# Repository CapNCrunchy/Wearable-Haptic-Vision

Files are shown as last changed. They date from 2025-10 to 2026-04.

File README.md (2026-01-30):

# Wearable-Haptic-Vision
Capstone project for UF CpE

# Project Architecture
"Wearable Haptic Vision" is a device that uses a wearable tactile display to inform the wearer about their surroundings by receiving object distance information. It will capture LiDAR depth information and utilize a Raspberry controller unit to make the wearable pressure waistband react according to an object's distance and direction.

## Pressure Waistband
The waistband will have embedded inflatable nodes that each have tubing connecting to a main housing unit that will hold the intake/exhaust controls (logic circuitry, pressure sensors, raspberry pi). There are 8 nodes that go across the waist and each will inflate according to the corresponding lidar information. For example, if an object is very close to the right side of the Lidar then the nodes on the right side will inflate to the max to represent the closest object. The inverse is also true that an object that is far away will be represented by a very deflated node.

## LiDAR Application
It is an iOS swift application taht utilizes the iphone built in LiDAR to retrieve location and distance information. It takes it as a full image map and then averages the values within the corresponding divisions. This is sent to the Raspberry Pi controller via BLE.

## Controller
The Raspberry Pi takes the lidar data and simplifies it into four states by distance. It then sends this data to the pressure regulator logic which switches between intake and exhaust to get to the correct state. This gives each node four distance/pressure states. 

# Completed Work 
- BLE reciever and Swift application connection
- Infalte/deflate valves for nodes
- Inflate/deflate Schematics w/ Rasperbery pi & modules
- Swift IOS application to interface with LIDAR
- Schematics and models for the vest & soft 3d-printed nodes

# Known Bugs/WIP
The newest physical model of inflatables and circuitry is still waiting to be printed.

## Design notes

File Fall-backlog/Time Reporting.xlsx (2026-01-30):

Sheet: Sheet1
Name | Date | Punch In | Punch Out | Description of Work
Connor | 2025-10-10 | 13:00:00 | 17:00:00 | Research on vest module options
Nico | 2025-10-14 | 17:00:00 | 18:00:00 | Research on sensor options for depth estimation, reaching out to researcher and consultants
Elias | 2025-10-16 | 12:30:00 | 12:55:00 | Researching interfacing with the built in iPhone lidar through swift and libraries and reaching out to MIT researchers related to our project
Connor | 2025-10-18 | 1:00:00 | 1:45:00 | Ordering parts and Outreach
Nico | 2025-10-24 | 15:00:00 | 19:00:00 | Researching and designing vest and soft nodes
Connor | 2025-10-24 | 20:30:00 | 22:00:00 | Hardware setup
Elias | 2025-10-24 | 21:00:00 | 0:00:00 | Reseraching and test runngin setting up Connection with Pi to iPhone through BLE
Shiner | 2025-10-24 | 22:00:00 | 0:45:00 | Researching PI and BLE
Elias | 2025-10-25 | 14:00:00 | 17:00:00 | Successfully configure Bluetooth on the Raspberry Pi 5
Shiner | 2025-10-25 | 14:00:00 | 17:00:00 | Troubleshooting iPhone and Pi bluetooth connection
Connor | 2025-10-25 | 17:00:00 | 19:00:00 | Researching Microcontroller feedback loop
Nico | 2025-10-25 | 17:00:00 | 19:00:00 | Designing soft nodes
Elias | 2025-10-25 | 18:00:00 | 22:00:00 | Deep Dive into Blue with Raspberry Pi reading documentation from argenox.com attempted some barebones scripts
Connor | 2025-10-26 | 5:00:00 | 10:00:00 | Soldering smd components. Microcontroller setup
Nico | 2025-10-26 | 13:00:00 | 14:00:00 | Designing and outreach
Shiner | 2025-10-26 | 16:00:00 | 19:00:00 | Testing and finishing up the BLE connection
Nico | 2025-10-26 | 17:00:00 | 23:00:00 | Cleaning up models and researching materials
Connor | 2025-10-26 | 16:00:00 | 22:30:00 | Full setup for a single node and schematic design
Shiner | 2025-10-26 | 19:15:00 | 21:30:00 | Confirming iPhone connection to Pi is seamless and efficient and cleaning up
Elias | 2025-10-26 | 14:00:00 | 18:30:00 | Finally Fixed WiFi problem with the Pi had to add Wifi Sharing from my laptop through the correct ethernet port updated some code to have correct logging functionality
Elias | 2025-10-26 | 19:15:00 | 21:30:00 | Completed the BLE receiver code and successfully demonstrated it
Connor | 2025-11-02 | 10:00:00 | 12:00:00 | Tubing set up
Connor | 2025-11-06 | 5:00:00 | 17:00:00 | Tubing, breadboarding, and physical prototype skeleton
Shiner | 2025-11-06 | 15:00:00 | 17:30:00 | Reviewing BLE connection and researching BLE GATT for Pi to microcontroller setup
Elias | 2025-11-07 | 16:00:00 | 21:00:00 | Research and reviewed SPI communication between the Pi and feather microcontroller and created a skeleton code template for storing the JSON payload
Nico | 2025-11-08 | 0:00:00 | 4:00:00 | Tubing and pneumatics setup/ math
Shiner | 2025-11-08 | 14:00:00 | 17:15:00 | Looked at skeleton code for storing JSON payload and researched how to incorporate it into microcontroller
Nico | 2025-11-09 | 11:00:00 | 13:00:00 | Consulting and research
Shiner | 2025-11-10 | 12:00:00 | 17:30:00 | Investigated and researched methods for converting LiDAR proximity values into discrete pressure levels based on actuator constraints
Elias | 2025-11-11 | 11:00:00 | 17:00:00 | Did in depth review of gRPC - Protobuf in case we needed to have a server for observation alongside our BLE
Shiner | 2025-11-11 | 16:00:00 | 20:00:00 | Understanding Rust language and tooling to prepare for receiver implementation
Shiner | 2025-11-11 | 21:00:00 | 23:30:00 | Reviewed BLE constraints for transmitting LiDAR grid data and compared JSON vs compact binary formats to prepare for later implementation.
Nico | 2025-11-13 | 14:30:00 | 18:00:00 | Redesigning node and research on flat pneumatic actuator
Shiner | 2025-11-13 | 19:00:00 | 22:00:00 | Researched JSON deserialization approaches and example 2D array validation techniques in Rust
Nico | 2025-11-14 | 1:00:00 | 3:00:00 | Assembly of pneumatics
Elias | 2025-11-14 | 14:00:00 | 18:00:00 | Attempted to solve connections issues with the pi and computers which we trying to develope with, bought a new hdmi cable which was incorrect, then finally returned it and bought a micro hdmi cable for the pi and solved all dev issues
Connor | 2025-11-14 | 17:30:00 | 18:00:00 | Micro controller code
Shiner | 2025-11-14 | 20:00:00 | 0:00:00 | Reviewed microcontroller code and researched the correct 2 value state patterns needed to support four pressure levels per node.
Connor | 2025-11-15 | 12:30:00 | 19:00:00 | Lab testing with compressed air and end to end connections
Shiner | 2025-11-15 | 14:00:00 | 20:00:00 | Implemented and completed JSON parsing, grid validation, and node state mapping, debugged for a while to fix issue with listening on wrong inferface
Elias | 2025-11-15 | 15:00:00 | 20:00:00 | Reseraching SPI protocols and did very extensive debugging to finally discover we were listening on if00 not if01
Nico | 2025-11-15 | 22:00:00 | 2:00:00 | Flat Pneumatic casting
Nico | 2025-11-16 | 14:00:00 | 19:00:00 | Testing first rounds of pneumatic casts and casting 2nd round
Elias | 2025-11-16 | 15:00:00 | 20:30:00 | Attempting to develope a more effeciently threaded Rust file to reduce the latency from the iphone down to the communication chain to the microcontroller

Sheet: Colin Hours
Start Date | Start Time | End Date | End Time | Duration (h) | Description
14/11/2025 | 15:00:00 | 14/11/2025 | 19:00:00 | 4:00:00 | Helped test LiDAR application + BLE receiver functionality in tandem with the pressure node system
14/11/2025 | 10:00:00 | 14/11/2025 | 17:00:00 | 7:00:00 | Implemented LiDAR + node grid processing in the iPhone application, fixed BLE transmissions with Raspberry Pi
13/11/2025 | 14:00:00 | 13/11/2025 | 17:00:00 | 3:00:00 | Researched LiDAR implementation methods and helped set up Raspberry Pi in lab
26/10/2025 | 13:00:00 | 26/10/2025 | 16:00:00 | 3:00:00 | Finished BLE transmissions
24/10/2025 | 11:00:00 | 24/10/2025 | 13:00:00 | 2:00:00 | Set up remote connections to Raspberry Pi for debug, set up user accounts for others to access
23/10/2025 | 12:00:00 | 23/10/2025 | 16:00:00 | 4:00:00 | Researched methods for receiving BLE messages, developed prototype receiving for verifying interface
20/10/2025 | 12:00:00 | 20/10/2025 | 14:30:00 | 2:30:00 | Develop initial LiDAR interface with BLE discovery functionality
19/10/2025 | 10:30:00 | 19/10/2025 | 12:00:00 | 1:30:00 | Initialize swift project, documentation reading (Swift UI and CoreBluetooth SDK)
18/10/2025 | 15:00:00 | 18/10/2025 | 15:30:00 | 0:30:00 | Provisioned Raspberry Pi 5 with Raspberry Pi OS Lite, configured and troubleshooted SSH connectivity
18/10/2025 | 11:00:00 | 18/10/2025 | 14:00:00 | 3:00:00 | Formulated problem of projecting LiDAR depth map to an i x j pressure grid, researched ways of extracting LiDAR depth map from iOS app, drafted high-level architecture for system
16/10/2025 | 13:00:00 | 16/10/2025 | 16:00:00 | 3:00:00 | Researched communication methods for iPhone and Raspberry Pi, compared approaches for continuous data streaming and discrete sensor commands from iPhone LiDAR

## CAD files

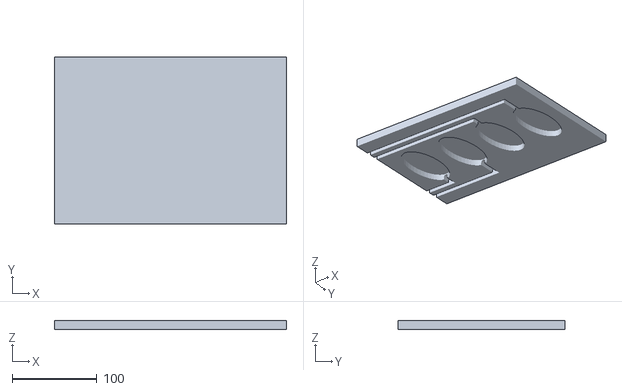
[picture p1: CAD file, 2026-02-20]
3d-models-drawings/new_models/grid nodes assembly file/Assembly 1 - tpu.stl
274.0 x 197.8 x 11.0

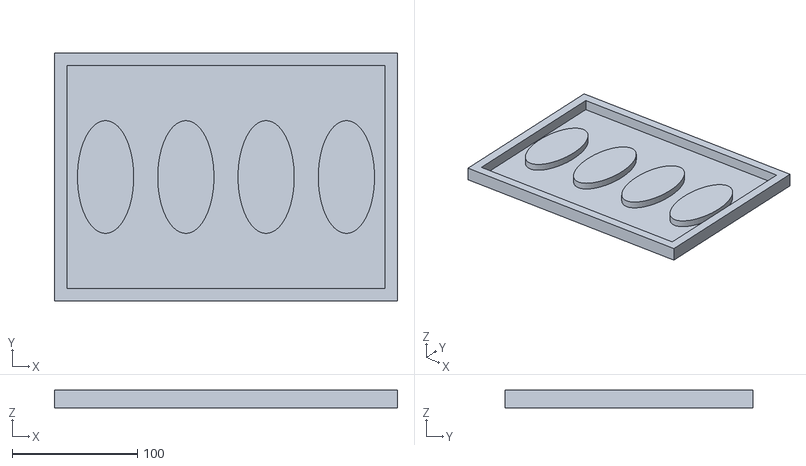
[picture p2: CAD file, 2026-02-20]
3d-models-drawings/new_models/grid nodes assembly file/Assembly 1 - silicone.stl
274.0 x 197.8 x 14.0

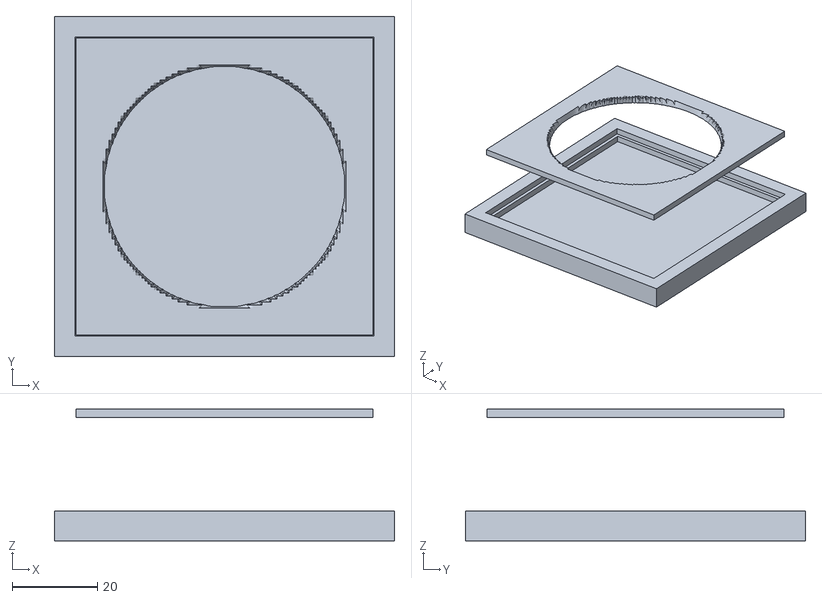
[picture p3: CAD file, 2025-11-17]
3d-models-drawings/flat_actuators_both20251113-43-4bq0js.stl
80.0 x 80.0 x 31.0

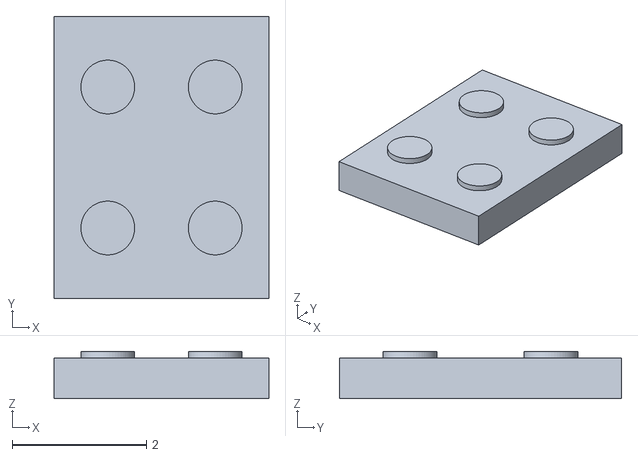
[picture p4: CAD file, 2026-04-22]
3d-models-drawings/new_models/external-ui-remote-v.01.stl
3.20 x 4.20 x 0.7

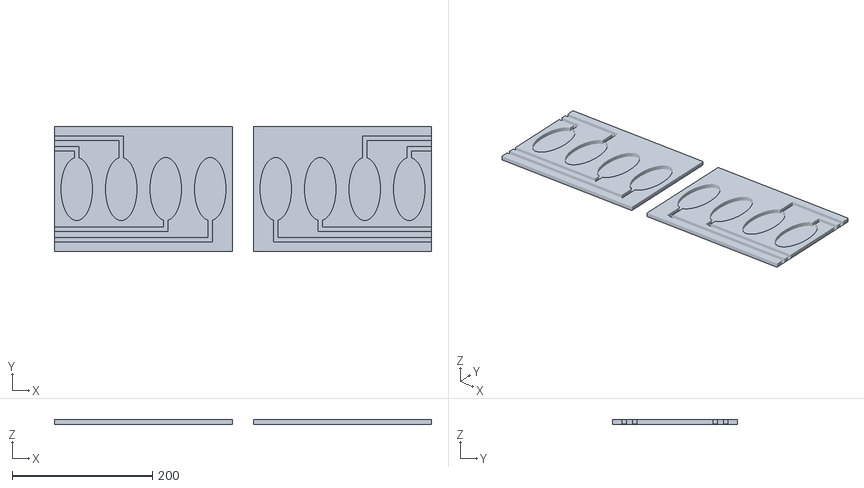
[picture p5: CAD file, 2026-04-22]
3d-models-drawings/new_models/grid nodes assembly file/new-grid-8.stl
538.0 x 177.8 x 6.50

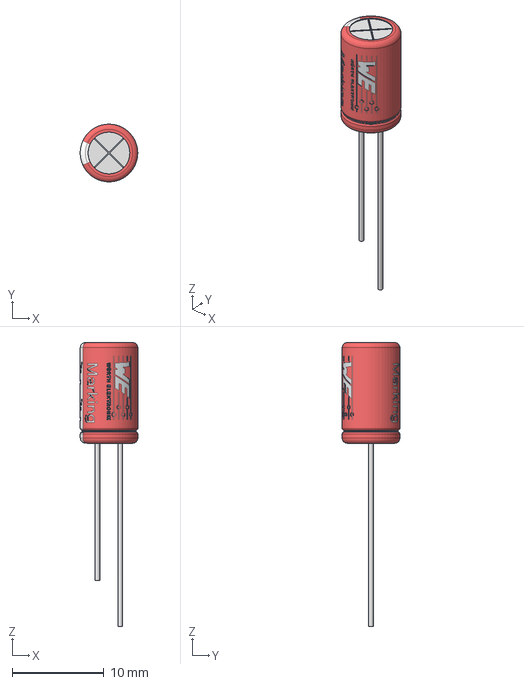
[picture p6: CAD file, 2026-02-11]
hardware/WHV_design/additional_footprints/860040573004/WCAP-ATUL_6.3X11.step
6.29 x 6.30 x 31.0 mm

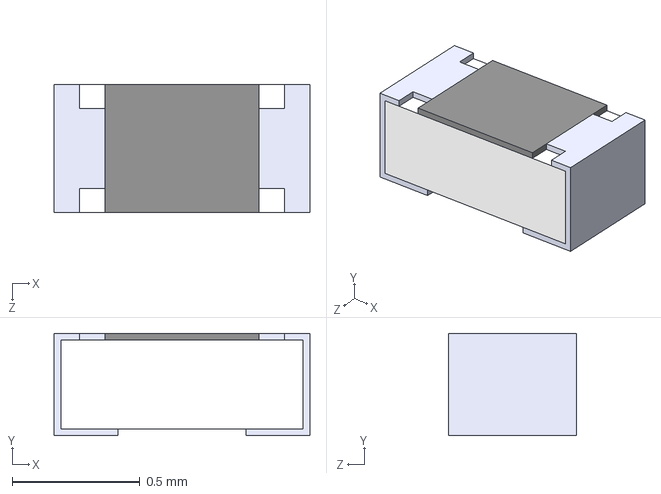
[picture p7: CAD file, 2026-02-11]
hardware/WHV_design/additional_footprints/RC0402FR_07210RL/RC0402FR-07210RL.step
1.00 x 0.4 x 0.5 mm

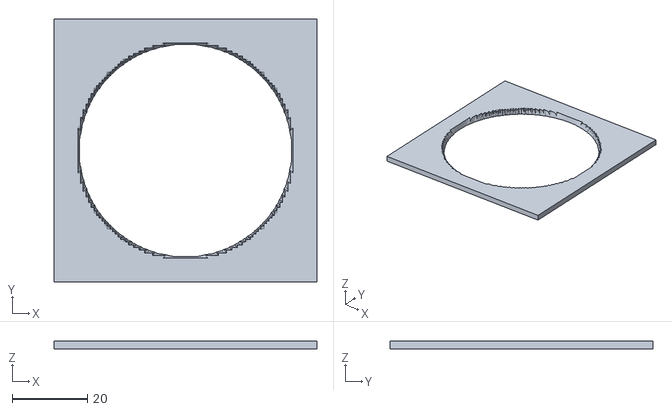
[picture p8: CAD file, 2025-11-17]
3d-models-drawings/flat_actuators_second20251113-43-1qi1enx.stl
70.0 x 70.0 x 2.00

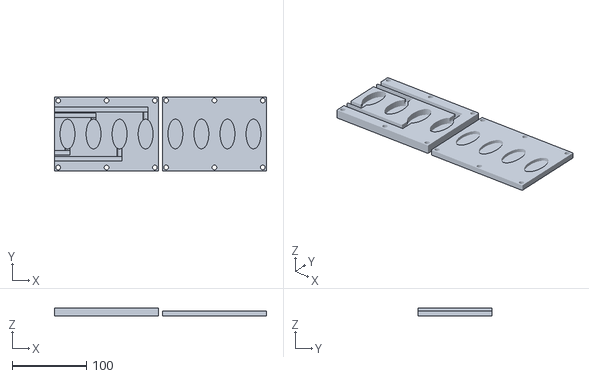
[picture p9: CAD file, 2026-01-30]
3d-models-drawings/new_models/grid_nodes_edited_v1.stl
285.1 x 100.1 x 11.4

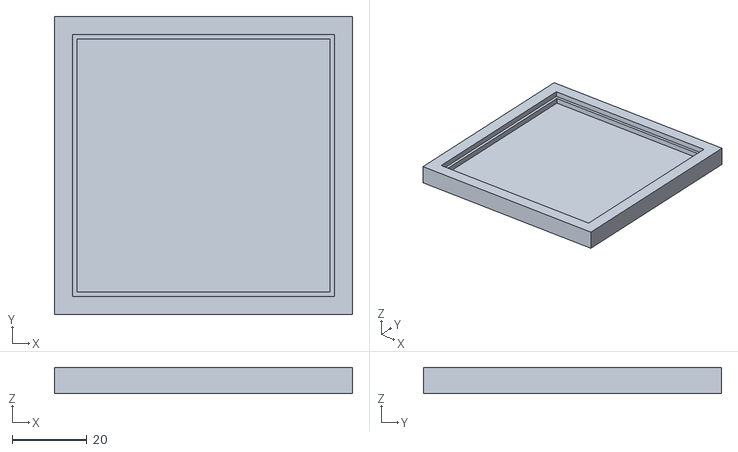
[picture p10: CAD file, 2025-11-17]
3d-models-drawings/flat_actuators_first20251113-43-1jmwba1.stl
80.0 x 80.0 x 7.00

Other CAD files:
3d-models-drawings/soft_pressure_node_part.sldprt
3d-models-drawings/old_drawings/soft_pressure_node_part.sldprt

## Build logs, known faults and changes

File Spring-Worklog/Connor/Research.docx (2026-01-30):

1/28/26 – 1/29/26

Summary: Looked at compressed air options and compatibility. Explored a mutable and modular schematic for valve control and decided to reduce project scope to accommodate lower engineering complexities. Created designed pressure control circuit to cut out the microcontroller in favor of just the pi.

Compressed air Research:

https://www.vevor.com/diving-snorkeling-c_13730/vevor-mini-scuba-tank-0-5l-portable-diving-tank-for-underwater-breathing-reusable-lung-diving-cylinder-up-to-10-minut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

https://www.homedepot.com/p/VEVOR-PCP-Hand-Pump-4-Stage-30Mpa-4500-PSI-High-Pressure-PCP-Air-Rifile-Filling-Stirrup-Pump-for-Airguns-Scuba-Tank-SDQQCQB4000PSVH1RV0/3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

Circuit stuff:

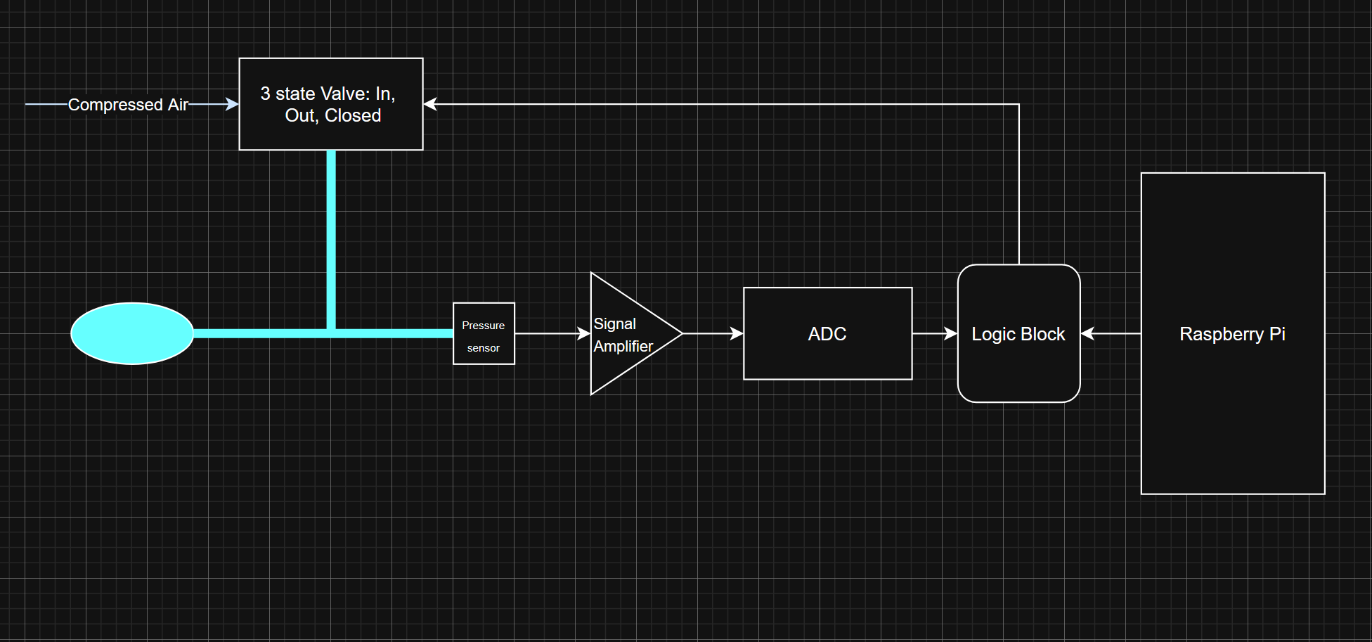
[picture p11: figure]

Handwritten notes and scratch:

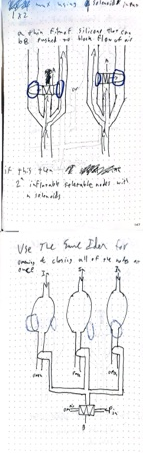
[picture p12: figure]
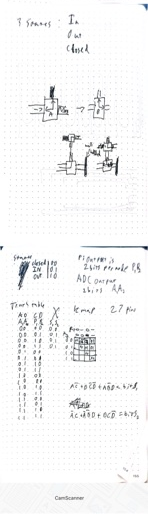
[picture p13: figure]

1/30

The schematic is the pressure sensor, amplifier, flash ADC, and logic to control the 2 valves for 3 states; IN, OUT, CLOSED.

The idea is that the pressure sensor output is put through amplifiers, then a differential and then put through a flash ADC to get the value in one of four states. The logic output is to control the two solenoid valves to create 3 different states. This is based on the ADC value and the raspberry Pi assigned value.

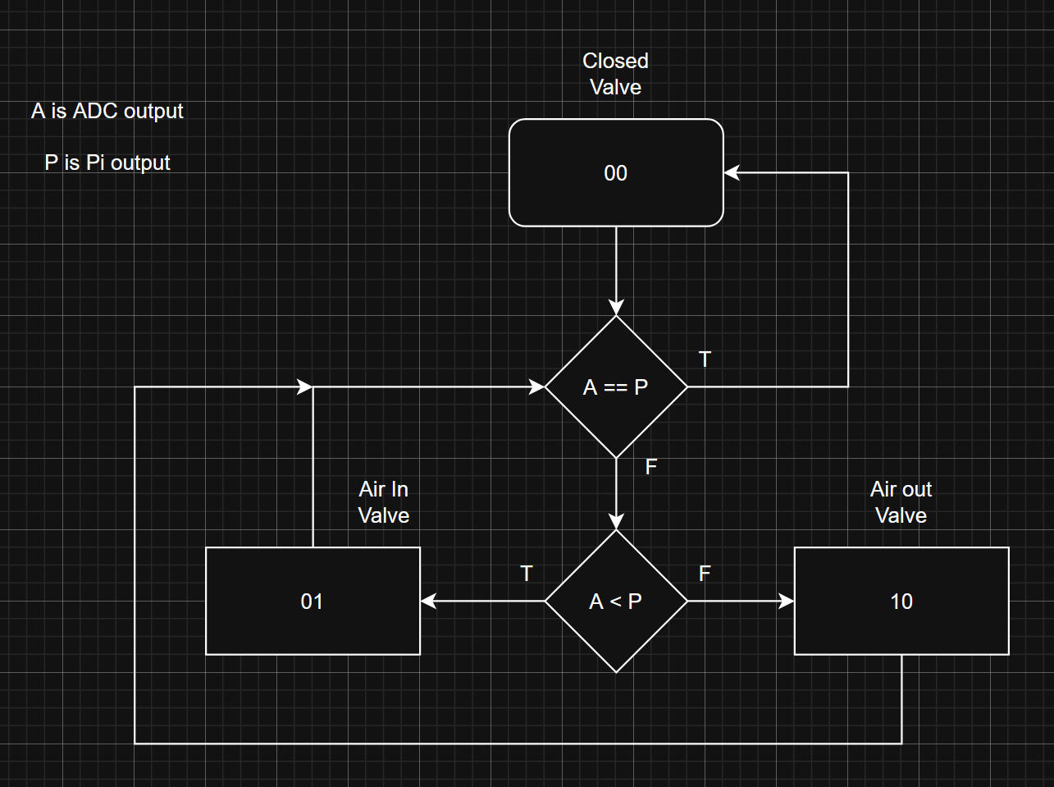
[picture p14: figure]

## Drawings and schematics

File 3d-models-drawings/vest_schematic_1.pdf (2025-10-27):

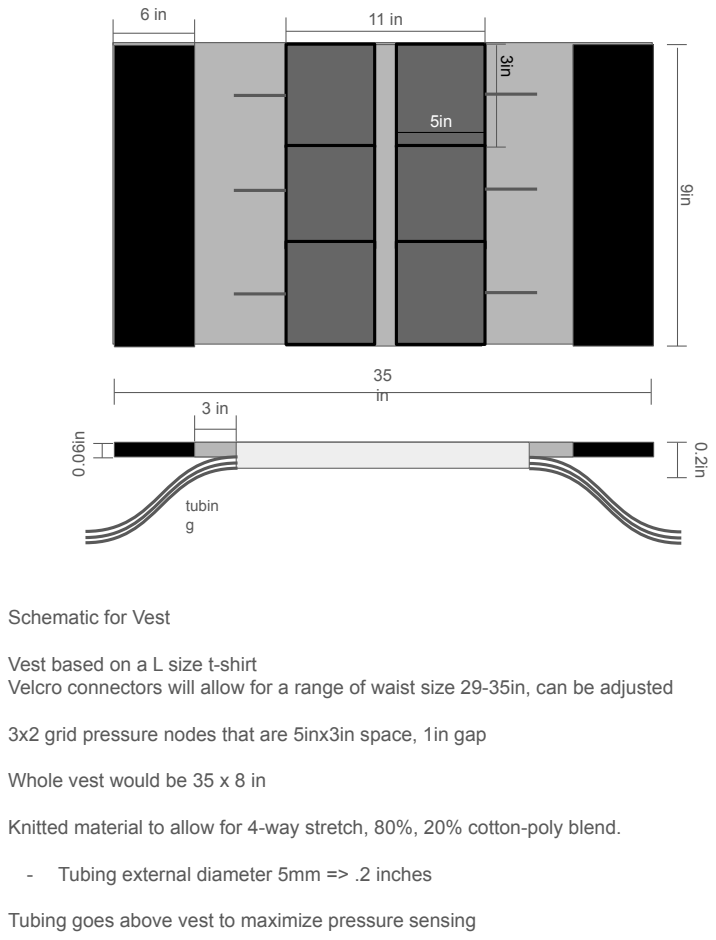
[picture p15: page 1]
tubin g

Schematic for Vest

Vest based on a L size t-shirt
Velcro connectors will allow for a range of waist size 29-35in, can be adjusted

3x2 grid pressure nodes that are 5inx3in space, 1in gap

Whole vest would be 35 x 8 in

Knitted material to allow for 4-way stretch, 80%, 20% cotton-poly blend.

- Tubing external diameter 5mm => .2 inches

Tubing goes above vest to maximize pressure sensing

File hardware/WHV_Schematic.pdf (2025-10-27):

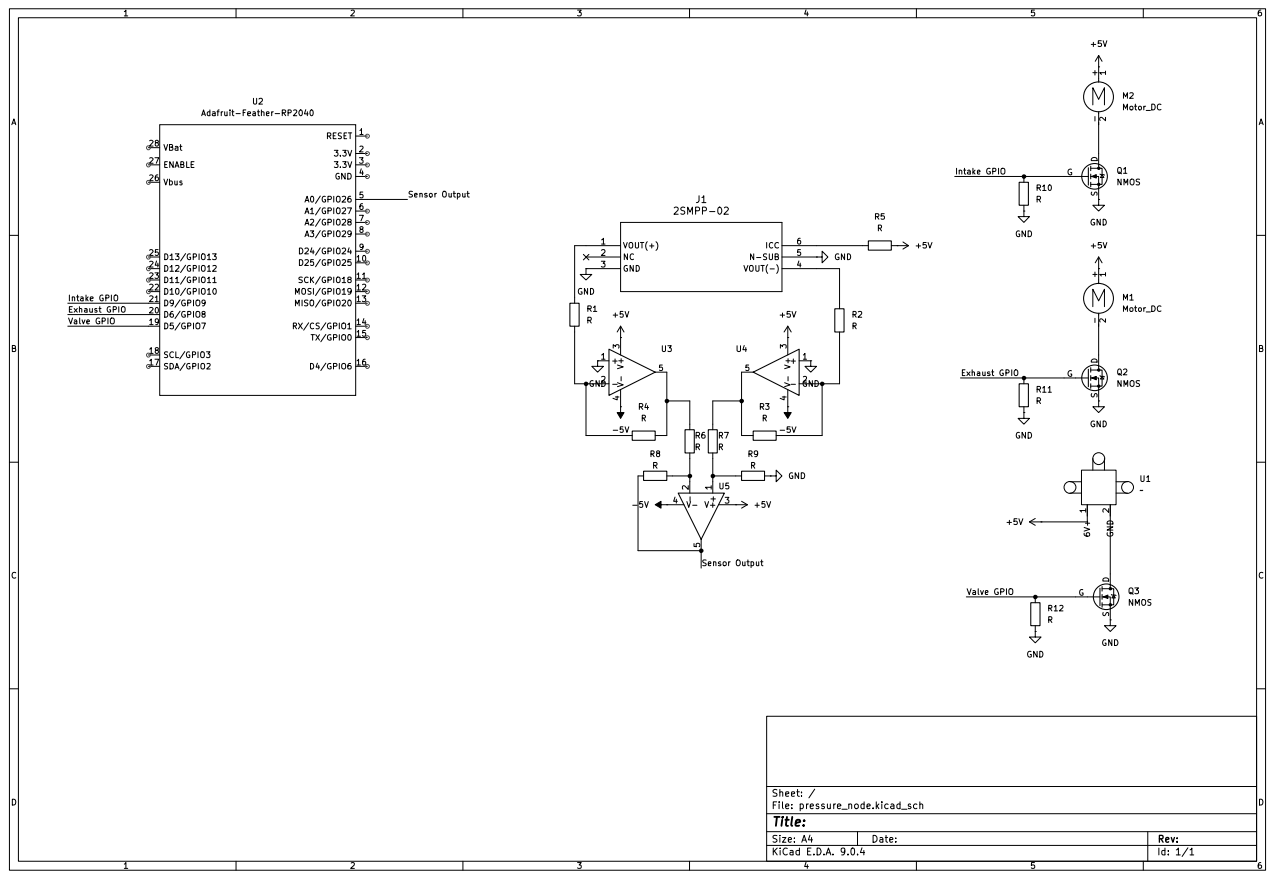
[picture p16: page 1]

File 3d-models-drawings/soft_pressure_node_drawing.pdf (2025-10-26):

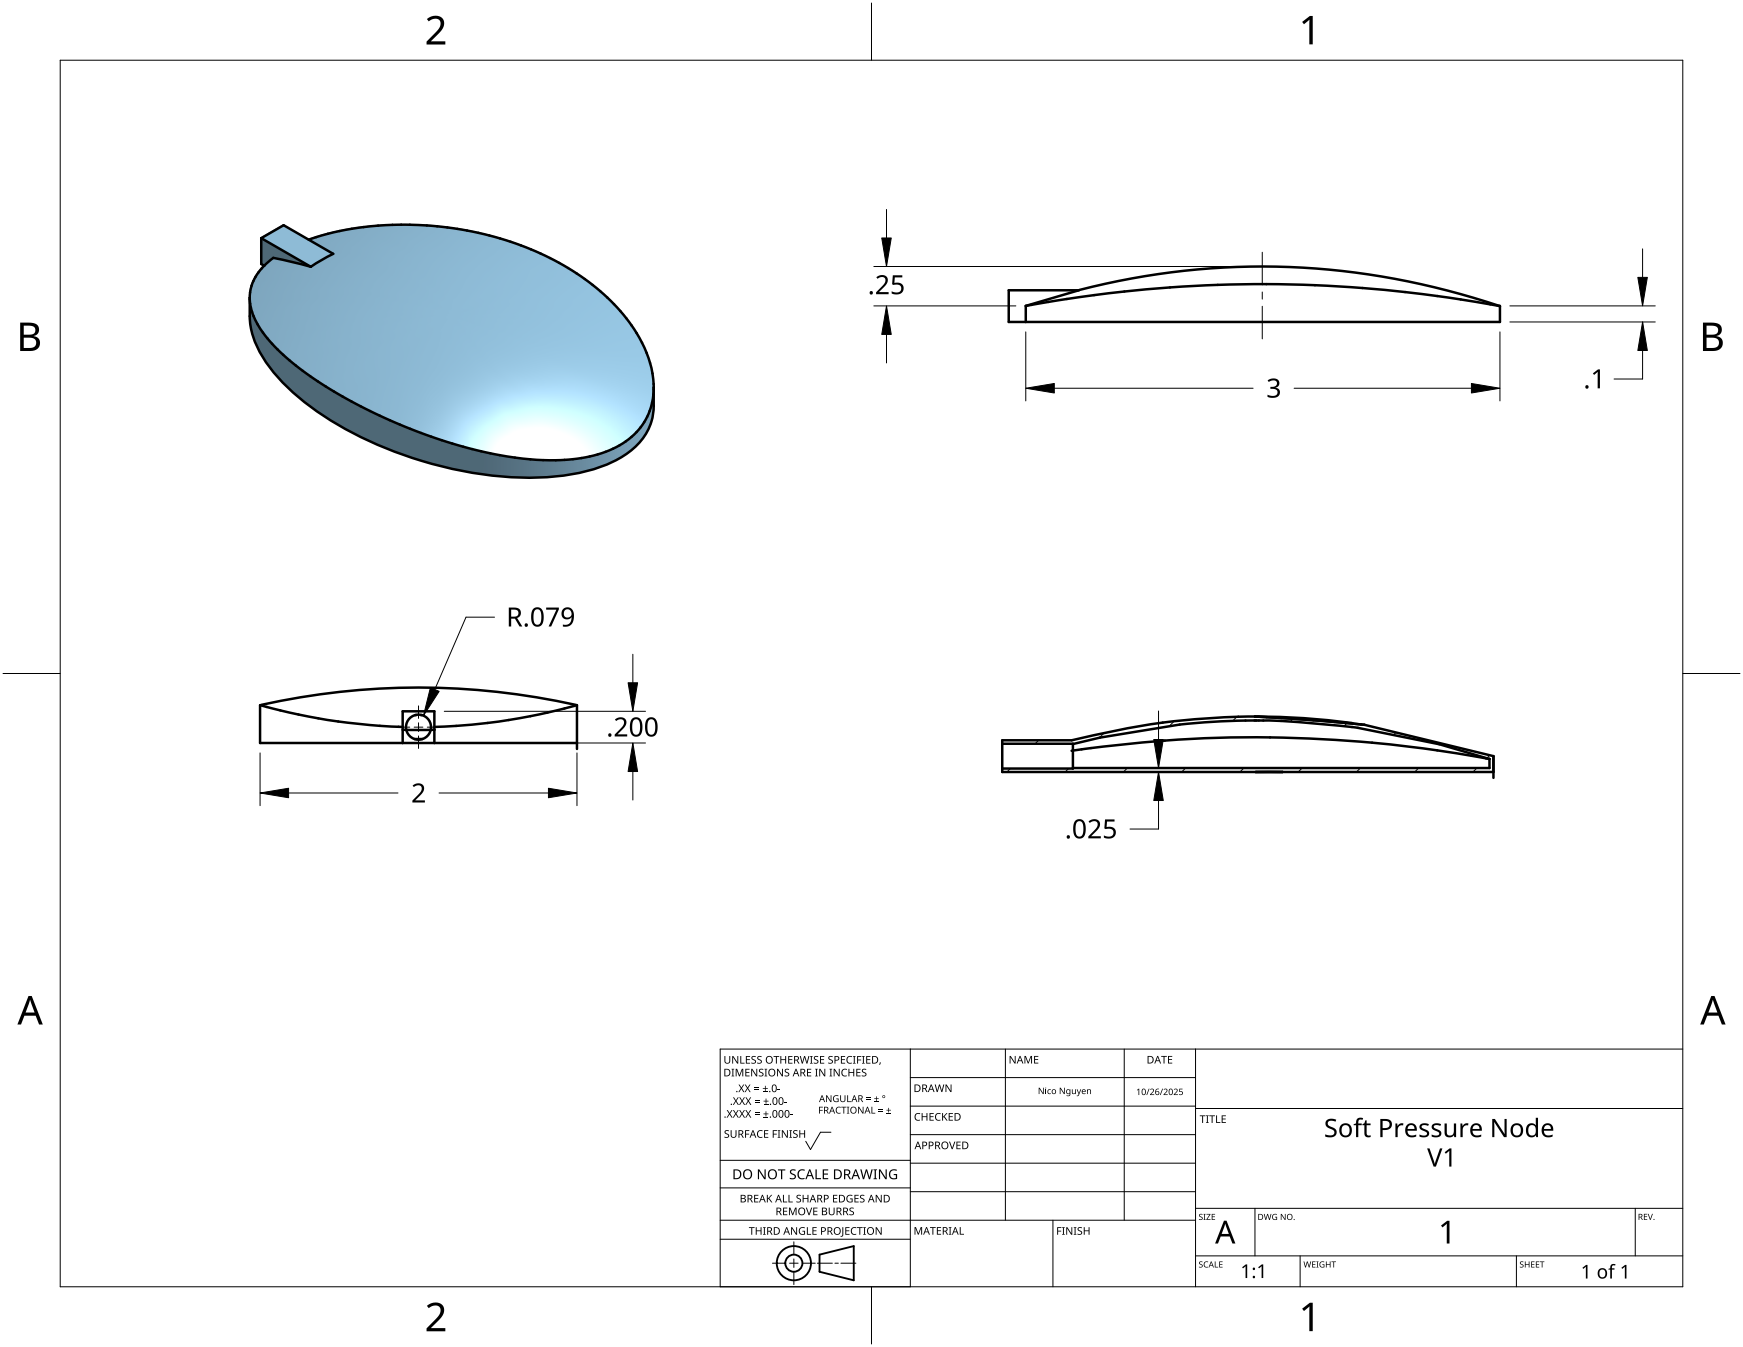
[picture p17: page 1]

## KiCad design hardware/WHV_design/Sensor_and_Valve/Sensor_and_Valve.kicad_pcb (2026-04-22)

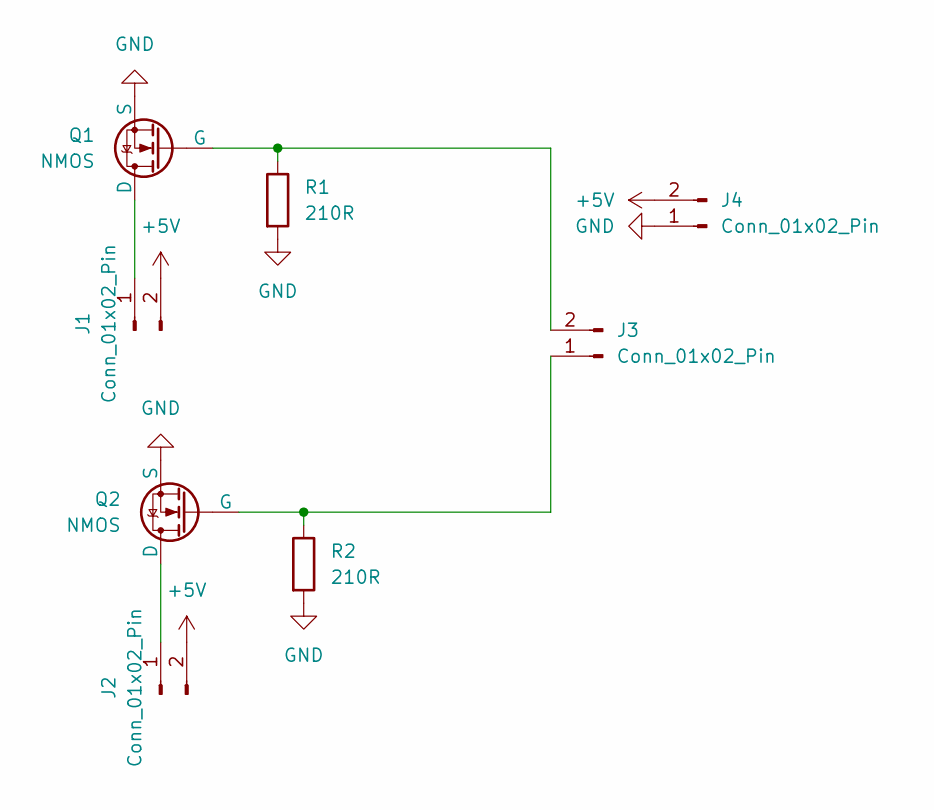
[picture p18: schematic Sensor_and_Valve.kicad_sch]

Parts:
J1, J2, J3, J4: Conn_01x02_Pin; JST_XH_B2B-XH-A_1x02_P2.50mm_Vertical
Q1, Q2: NMOS; SOT23_TOS
R1, R2: 210R; RESC1005X40N

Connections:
+5V: J1.2, J2.2, J4.2
GND: J4.1, Q1.3 (S), Q2.3 (S), R1.2, R2.2
unnamed: J1.1, Q1.1 (D)
unnamed: J2.1, Q2.1 (D)
unnamed: J3.1, Q2.2 (G), R2.1
unnamed: J3.2, Q1.2 (G), R1.1

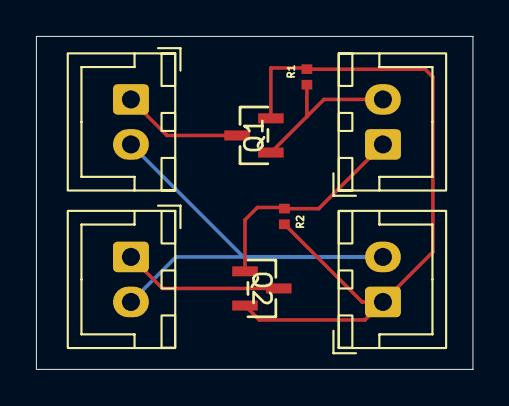
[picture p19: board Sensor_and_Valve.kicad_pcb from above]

Board: 2 copper layers, 24.2 x 18.5 mm, 8 parts (0 on the bottom side), 6 nets.

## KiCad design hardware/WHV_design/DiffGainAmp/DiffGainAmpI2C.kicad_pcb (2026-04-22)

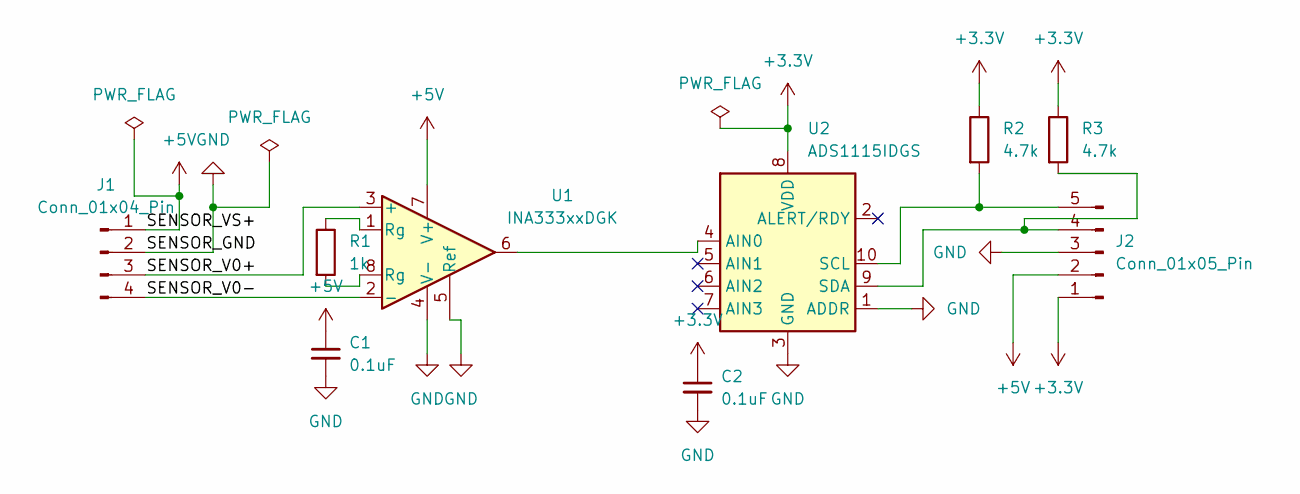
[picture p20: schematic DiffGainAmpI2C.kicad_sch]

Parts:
C1, C2: 0.1uF; C_0805_2012Metric
J1: Conn_01x04_Pin; PinHeader_1x04_P2.54mm_Vertical
J2: Conn_01x05_Pin; PinHeader_1x05_P2.54mm_Vertical
R1: 1k; R_0805_2012Metric
R2, R3: 4.7k; R_0805_2012Metric
U1: INA333xxDGK; VSSOP-8_3x3mm_P0.65mm
U2: ADS1115IDGS; VSSOP-10_3x3mm_P0.5mm

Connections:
+3.3V: C2.1, J2.1, R2.1, R3.1, U2.8 (VDD)
+5V: C1.1, J1.1, J2.2, U1.7 (V+)
/SENSOR_V0+: J1.3, U1.3 (+)
/SENSOR_V0-: J1.4, U1.2 (-)
GND: C1.2, C2.2, J1.2, J2.3, U1.4 (V-), U1.5 (Ref), U2.1 (ADDR), U2.3 (GND)
unnamed: J2.4, R3.2, U2.9 (SDA)
unnamed: J2.5, R2.2, U2.10 (SCL)
unnamed: R1.1, U1.1 (Rg)
unnamed: R1.2, U1.8 (Rg)
unnamed: U1.6, U2.4 (AIN0)

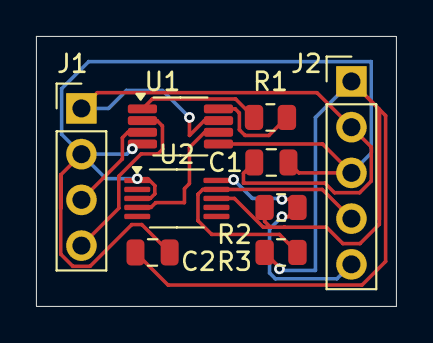
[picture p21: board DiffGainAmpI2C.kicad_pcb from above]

Board: 2 copper layers, 20.0 x 15.0 mm, 9 parts (0 on the bottom side), 10 nets.

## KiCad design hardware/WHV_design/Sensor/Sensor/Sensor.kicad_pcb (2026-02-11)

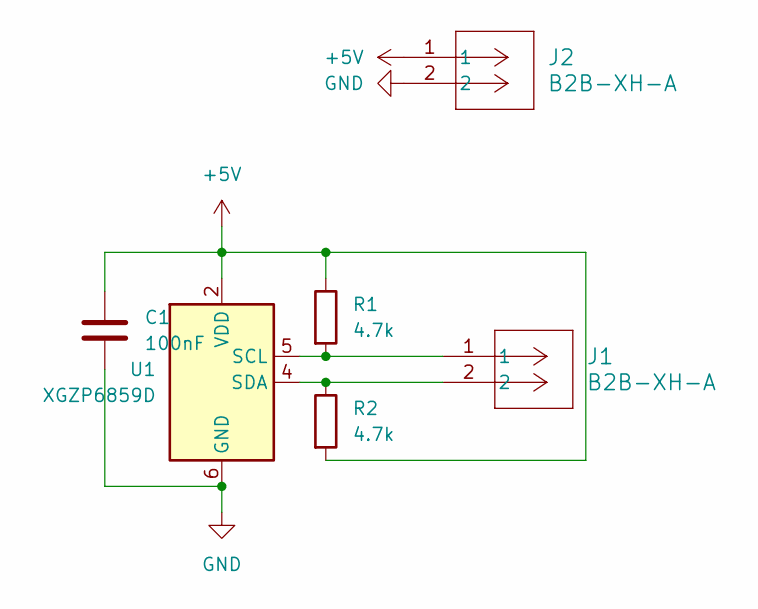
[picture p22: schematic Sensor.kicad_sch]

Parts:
C1: 100nF; WCAP-ATUL_6.3X11_DXL_
J1, J2: B2B-XH-A; CONN_B2B-XH-A_JST
R1, R2: 4.7k; RESC1005X40N
U1: XGZP6859D; CFSensor_XGZP6859D_7x7mm

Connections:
+5V: C1.1, J2.1, R1.1, R2.2, U1.2 (VDD)
GND: C1.2, J2.2, U1.6 (GND)
unnamed: J1.1, R1.2, U1.5 (SCL)
unnamed: J1.2, R2.1, U1.4 (SDA)

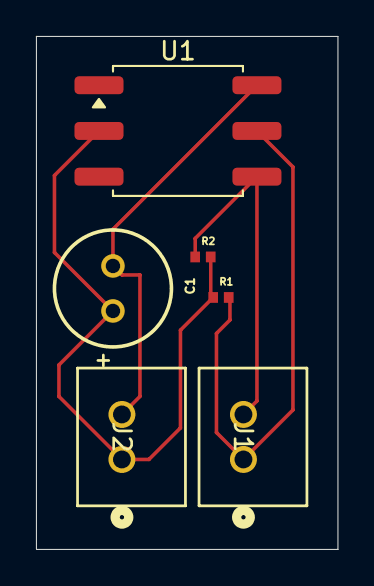
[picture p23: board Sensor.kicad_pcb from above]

Board: 2 copper layers, 16.8 x 28.5 mm, 6 parts (0 on the bottom side), 4 nets.

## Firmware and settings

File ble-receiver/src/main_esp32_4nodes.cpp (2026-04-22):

#include <BLEDevice.h>
#include <BLEServer.h>
#include <BLEUtils.h>
#include <BLE2902.h>
#include <Wire.h>

#define SERVICE_UUID "8b322909-2d3b-447b-a4d5-dfe0c009ec5a"
#define CHARACTERISTIC_RX "8b32290a-2d3b-447b-a4d5-dfe0c009ec5a"
#define CHARACTERISTIC_INFO "8b32290c-2d3b-447b-a4d5-dfe0c009ec5a"


#define SENSOR_SDA 25
#define SENSOR_SCL 26
#define XGZP_ADDRESS 0x6D
#define MUX_S0 32
#define MUX_S1 5
#define MUX_S2 33

const int NODE1_1 = 13; const int NODE1_2 = 14;
const int NODE2_1 = 18; const int NODE2_2 = 19;
const int NODE3_1 = 21; const int NODE3_2 = 22;
const int NODE4_1 = 23; const int NODE4_2 = 4;

BLEServer* pServer = NULL;
bool deviceConnected = false;
int currentStates[8] = {4, 4, 4, 4, 4, 4, 4, 4};
unsigned long lastSensorRead = 0;


void applyNodeState(int state, int pin1, int pin2) {
    if (state == 1) { 
        digitalWrite(pin1, LOW); digitalWrite(pin2, LOW);
    } else if (state == 2) {
        digitalWrite(pin1, LOW); digitalWrite(pin2, HIGH);
    } else if (state == 3) {
        digitalWrite(pin1, HIGH); digitalWrite(pin2, LOW);
    } else if (state == 4) { 
        digitalWrite(pin1, HIGH); digitalWrite(pin2, HIGH);
    } else {
        digitalWrite(pin1, LOW); digitalWrite(pin2, LOW); 
    }
}

int calculateState(float proximity) {
    if (isnan(proximity)) proximity = 0.0;
    if (proximity < 0.0) proximity = 0.0;
    if (proximity > 1.0) proximity = 1.0;
    if (proximity < 0.25) return 4;
    else if (proximity < 0.5) return 3;
    else if (proximity < 0.75) return 2;
    else return 1;
}

// Function to physically switch the 3x8 MUX
void setMuxChannel(int channel) {
    digitalWrite(MUX_S0, bitRead(channel, 0));
    digitalWrite(MUX_S1, bitRead(channel, 1));
    digitalWrite(MUX_S2, bitRead(channel, 2));
    delay(5); 
}

// Function to read a specific pressure sensor through the MUX
void readPressure(int channel) {
    setMuxChannel(channel);

    Wire1.beginTransmission(XGZP_ADDRESS);
    Wire1.write(0x30); 
    Wire1.write(0x0A); 
    if (Wire1.endTransmission() != 0) {
        Serial.printf("MUX Channel %d: No sensor responding.\n", channel);
        return;
    }

    delay(30);

    Wire1.beginTransmission(XGZP_ADDRESS);
    Wire1.write(0x06);
    Wire1.endTransmission(false);
    
    Wire1.requestFrom((uint16_t)XGZP_ADDRESS, (uint8_t)3);
    
    if (Wire1.available() == 3) {
        uint32_t dataHigh = Wire1.read();
        uint32_t dataMid  = Wire1.read();
        uint32_t dataLow  = Wire1.read();

        int32_t rawPressure = (dataHigh << 16) | (dataMid << 8) | dataLow;
        if (rawPressure & 0x800000) rawPressure -= 0x1000000;

        Serial.printf("Sensor on MUX Channel %d | Raw Pressure: %d\n", channel, rawPressure);
    }
}


class MyCallbacks: public BLECharacteristicCallbacks {
    void onWrite(BLECharacteristic *pCharacteristic) {
        uint8_t* pData = pCharacteristic->getData();
        size_t length = pCharacteristic->getLength();
        
        // We check for 32 bytes so the iOS app doesn't need to be rewritten
        if (length >= 32) {
            float* incomingDistances = (float*)pData;
            int newStates[8] = {4, 4, 4, 4, 4, 4, 4, 4};
            
            for (int i = 0; i < 8; i++) {
                newStates[i] = calculateState(incomingDistances[i]);
            }

            bool stateChanged = false;
            for (int i = 0; i < 8; i++) {
                if (newStates[i] != currentStates[i]) {
                    stateChanged = true;
                    currentStates[i] = newStates[i];
                }
            }

            if (stateChanged) {
                // WE ONLY ACTUATE THE FIRST 4 NODES HERE
                applyNodeState(currentStates[0], NODE1_1, NODE1_2);
                applyNodeState(currentStates[1], NODE2_1, NODE2_2);
                applyNodeState(currentStates[2], NODE3_1, NODE3_2);
                applyNodeState(currentStates[3], NODE4_1, NODE4_2);
                
                Serial.printf("Vest Updated: N1:%d N2:%d N3:%d N4:%d (Nodes 5-8 Ignored)\n", 
                              currentStates[0], currentStates[1], currentStates[2], currentStates[3]);
            }
        }
    }
};

class MyServerCallbacks: public BLEServerCallbacks {
    void onConnect(BLEServer* pServer) {
      deviceConnected = true;
      Serial.println("iPhone Connected!");
    };
    void onDisconnect(BLEServer* pServer) {
      deviceConnected = false;
      Serial.println("iPhone Disconnected. Deflating Nodes 1-4.");
      
      // Deflate only the 4 nodes safely
      int allPins[] = {NODE1_1, NODE1_2, NODE2_1, NODE2_2, NODE3_1, NODE3_2, NODE4_1, NODE4_2};
      for (int i = 0; i < 8; i++) {
          digitalWrite(allPins[i], HIGH); 
      }
      pServer->startAdvertising(); 
    }
};

void setup() {
    Serial.begin(115200);

    
    pinMode(MUX_S0, OUTPUT);
    pinMode(MUX_S1, OUTPUT);
    pinMode(MUX_S2, OUTPUT);

    
    int allPins[] = {NODE1_1, NODE1_2, NODE2_1, NODE2_2, NODE3_1, NODE3_2, NODE4_1, NODE4_2};
    for (int i = 0; i < 8; i++) {
        pinMode(allPins[i], OUTPUT);
        digitalWrite(allPins[i], HIGH); 
    }
    Serial.println("Direct Valve Pins for Nodes 1-4 Initialized!");

    
    Wire1.begin(SENSOR_SDA, SENSOR_SCL);
    Serial.println("I2C Sensor Bus Initialized on Pins 25 & 26.");

    
    BLEDevice::init("WHV Haptic Receiver"); 
    pServer = BLEDevice::createServer();
    pServer->setCallbacks(new MyServerCallbacks());
    BLEService *pService = pServer->createService(SERVICE_UUID);
    BLECharacteristic *pRxCharacteristic = pService->createCharacteristic(
                                             CHARACTERISTIC_RX,
                                             BLECharacteristic::PROPERTY_WRITE | BLECharacteristic::PROPERTY_WRITE_NR
                                           );
    pRxCharacteristic->setCallbacks(new MyCallbacks());
    BLECharacteristic *pInfoCharacteristic = pService->createCharacteristic(
                                             CHARACTERISTIC_INFO,
                                             BLECharacteristic::PROPERTY_READ
                                           );
    pInfoCharacteristic->setValue("WHV ESP32 v5.1 (4-Node Test)");
    pService->start();
    BLEAdvertising *pAdvertising = BLEDevice::getAdvertising();
    pAdvertising->addServiceUUID(SERVICE_UUID);
    pAdvertising->setScanResponse(true);
    pAdvertising->setMinPreferred(0x06);  
    pAdvertising->setMinPreferred(0x12);
    BLEDevice::startAdvertising();
    
    Serial.println("ESP32 System Ready!");
}

void loop() {
    // Read the pressure sensors every 500 milliseconds
    if (millis() - lastSensorRead > 500) {
        
        
        readPressure(0);
        
        
        readPressure(1);
        
        Serial.println("---");
        lastSensorRead = millis();
    }
    
    // Tiny delay to keep the background BLE tasks happy
    delay(10); 
}

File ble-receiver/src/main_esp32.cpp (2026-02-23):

#include <BLEDevice.h>
#include <BLEServer.h>
#include <BLEUtils.h>
#include <BLE2902.h>

#define SERVICE_UUID "8b322909-2d3b-447b-a4d5-dfe0c009ec5a"
#define CHARACTERISTIC_RX "8b32290a-2d3b-447b-a4d5-dfe0c009ec5a"
#define CHARACTERISTIC_INFO "8b32290c-2d3b-447b-a4d5-dfe0c009ec5a"

// ESP32 Pin Mappings
const int ALL_NODES_ON = 2; 

const int NODE1_1 = 13; const int NODE1_2 = 12;
const int NODE2_1 = 14; const int NODE2_2 = 27;
const int NODE3_1 = 26; const int NODE3_2 = 25;
const int NODE4_1 = 33; const int NODE4_2 = 32;
const int NODE5_1 = 15; const int NODE5_2 = 4;

// Moved away from PSRAM crash pins (16 & 17) to safe pins (5 & 23)
const int NODE6_1 = 5;  const int NODE6_2 = 23;

const int NODE7_1 = 18; const int NODE7_2 = 19;
const int NODE8_1 = 21; const int NODE8_2 = 22;

BLEServer* pServer = NULL;
bool deviceConnected = false;

// Helper
void applyNodeState(int state, int pin1, int pin2) {
    if (state == 1) { // Max Inflation
        digitalWrite(pin1, LOW);
        digitalWrite(pin2, LOW);
    } else if (state == 2) {
        digitalWrite(pin1, LOW);
        digitalWrite(pin2, HIGH);
    } else if (state == 3) {
        digitalWrite(pin1, HIGH);
        digitalWrite(pin2, LOW);
    } else if (state == 4) { // Deflated / Safe
        digitalWrite(pin1, HIGH);
        digitalWrite(pin2, HIGH);
    } else {
        digitalWrite(pin1, LOW);
        digitalWrite(pin2, LOW); 
    }
}

// Math Translation: Floats (0.0-1.0) to States (1-4)
int calculateState(float proximity) {
    if (isnan(proximity)) proximity = 0.0;
    if (proximity < 0.0) proximity = 0.0;
    if (proximity > 1.0) proximity = 1.0;

    if (proximity < 0.25) return 4;
    else if (proximity < 0.5) return 3;
    else if (proximity < 0.75) return 2;
    else return 1;
}

// Global array to remember the current state of the vest
int currentStates[8] = {4, 4, 4, 4, 4, 4, 4, 4};

// BLE Callback for when the iOS app sends raw float bytes
class MyCallbacks: public BLECharacteristicCallbacks {
    void onWrite(BLECharacteristic *pCharacteristic) {
        uint8_t* pData = pCharacteristic->getData();
        size_t length = pCharacteristic->getLength();

        
        // 8 floats * 4 bytes per float = 32 bytes
        if (length >= 32) {
            // Treat the raw byte array directly as an array of floats
            float* incomingDistances = (float*)pData;
            
            int newStates[8] = {4, 4, 4, 4, 4, 4, 4, 4};
            
            for (int i = 0; i < 8; i++) {
                newStates[i] = calculateState(incomingDistances[i]);
            }

            // Check if anything actually changed
            bool stateChanged = false;
            for (int i = 0; i < 8; i++) {
                if (newStates[i] != currentStates[i]) {
                    stateChanged = true;
                    currentStates[i] = newStates[i]; // Update our memory
                }
            }

            // Update only if changed
            if (stateChanged) {
                applyNodeState(currentStates[0], NODE1_1, NODE1_2);
                applyNodeState(currentStates[1], NODE2_1, NODE2_2);
                applyNodeState(currentStates[2], NODE3_1, NODE3_2);
                applyNodeState(currentStates[3], NODE4_1, NODE4_2);
                applyNodeState(currentStates[4], NODE5_1, NODE5_2);
                applyNodeState(currentStates[5], NODE6_1, NODE6_2);
                applyNodeState(currentStates[6], NODE7_1, NODE7_2);
                applyNodeState(currentStates[7], NODE8_1, NODE8_2);
                
                Serial.printf("Vest Updated: %d %d %d %d %d %d %d %d\n", 
                              currentStates[0], currentStates[1], currentStates[2], currentStates[3], 
                              currentStates[4], currentStates[5], currentStates[6], currentStates[7]);
            }
        } else if (length > 0) {
            Serial.printf("Error: Expected 32 bytes (8 floats), but received %d bytes\n", length);
        }
    }
};

class MyServerCallbacks: public BLEServerCallbacks {
    void onConnect(BLEServer* pServer) {
      deviceConnected = true;
      Serial.println("iPhone Connected!");
    };
    void onDisconnect(BLEServer* pServer) {
      deviceConnected = false;
      Serial.println("iPhone Disconnected. Resetting all nodes to State 4.");
      
      int deflated = 4; 
      applyNodeState(deflated, NODE1_1, NODE1_2);
      applyNodeState(deflated, NODE2_1, NODE2_2);
      applyNodeState(deflated, NODE3_1, NODE3_2);
      applyNodeState(deflated, NODE4_1, NODE4_2);
      applyNodeState(deflated, NODE5_1, NODE5_2);
      applyNodeState(deflated, NODE6_1, NODE6_2);
      applyNodeState(deflated, NODE7_1, NODE7_2);
      applyNodeState(deflated, NODE8_1, NODE8_2);
      
      pServer->startAdvertising(); 
    }
};

void setup() {
    Serial.begin(115200);

    int allPins[] = {ALL_NODES_ON, NODE1_1, NODE1_2, NODE2_1, NODE2_2, 
                     NODE3_1, NODE3_2, NODE4_1, NODE4_2, NODE5_1, 
                     NODE5_2, NODE6_1, NODE6_2, NODE7_1, NODE7_2, NODE8_1, NODE8_2};
                     
    for (int i = 0; i < 17; i++) {
        pinMode(allPins[i], OUTPUT);
        digitalWrite(allPins[i], HIGH); 
    }
    
    digitalWrite(ALL_NODES_ON, HIGH);

    BLEDevice::init("WHV Haptic Receiver"); 
    pServer = BLEDevice::createServer();
    pServer->setCallbacks(new MyServerCallbacks());

    BLEService *pService = pServer->createService(SERVICE_UUID);

    BLECharacteristic *pRxCharacteristic = pService->createCharacteristic(
                                             CHARACTERISTIC_RX,
                                             BLECharacteristic::PROPERTY_WRITE |
                                             BLECharacteristic::PROPERTY_WRITE_NR
                                           );
    pRxCharacteristic->setCallbacks(new MyCallbacks());

    BLECharacteristic *pInfoCharacteristic = pService->createCharacteristic(
                                             CHARACTERISTIC_INFO,
                                             BLECharacteristic::PROPERTY_READ
                                           );
    pInfoCharacteristic->setValue("WHV ESP32 Raw Float Receiver");

    pService->start();
    BLEAdvertising *pAdvertising = BLEDevice::getAdvertising();
    pAdvertising->addServiceUUID(SERVICE_UUID);
    pAdvertising->setScanResponse(true);
    pAdvertising->setMinPreferred(0x06);  
    pAdvertising->setMinPreferred(0x12);
    BLEDevice::startAdvertising();
    
    Serial.println("ESP32 BLE Server is up!");
}

void loop() {
    delay(1); 
}

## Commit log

2025-10-19 (lidar) init swift project
2025-10-20 (lidar) rough implementation of BluetoothManager + device scanning, untested
2025-10-20 (lidar) specify NSBluetoothAlwaysUsageDescription
2025-10-20 (lidar) scan based on state change
2025-10-20 (lidar) change min RSSI to be -60 so it can discover the pi
2025-10-26 (lidar) finish bluetooth connectivity sending mock data
2025-10-26 (lidar) actually stage the files before commit
2025-10-26 first draft of soft nodes w/ part and part drawing
    [soft_pressure_node_part.sldprt]
2025-10-26 Update main.rs to use correct bluer version
    [main.rs]
2025-10-27 schematic for vest
    mocked up on google slides, will work on 3d model but wanted to have a nice 2d layout fist
2025-10-27 vest schematic 1
    mocked up on google slides, will work on 3d model with pneumatic simulation. wanted to get an 2d schematic to potentially also start creating real mockups
2025-10-27 hardware schematics and datasheets
2025-11-14 (lidar) connections work, update state in UI
2025-11-14 (lidar) use specific writing characteristic, discover peripheral characteristics
2025-11-14 (lidar) camera permissions
2025-11-14 (lidar) use depth map view instead of BLE transmitter
2025-11-15 added individual pin values for each states
2025-11-15 wired gridmap to 4 states for uart node controller
2025-11-15 Rollback changes to main.rs due to build failures
    [main.rs]
2025-11-15 fixed process payload function
    [main.rs]
2025-11-15 added print statement to view raw bytes from array
2025-11-17 Pneumatic Assembly System V1
2025-11-17 molds/ stencils for flat pneumatic nodes
    [flat_actuators_both20251113-43-4bq0js.stl, flat_actuators_first20251113-43-1jmwba1.stl, flat_actuators_second20251113-43-1qi1enx.stl]
2026-01-30 exploration and redesign of hardware
    [Time Reporting.xlsx]
2026-01-30 added schematic for node regulator
    [WHV_design.kicad_pcb, WHV_design.kicad_sch]
2026-01-30 (lidar) data send toggling
2026-01-30 (lidar) begin on a new app view (claude-generated prototype)
2026-01-30 (lidar) split into mock and BLE devices / managers, apply to app view
2026-01-30 (lidar) add unique identifiers to mock devices
2026-01-30 (lidar) try building and deploying to testflight
2026-01-30 (lidar) allow workflow dispatches
2026-01-30 (lidar) specify ruby version
2026-01-30 (lidar) fix bad path
2026-01-30 (lidar) fix up paths
2026-01-30 (lidar) specify platform
2026-01-30 reorganized and newest model with tpu layers/ silicone layer.
    [flat_actuators_both20251113-43-4bq0js.stl, flat_actuators_first20251113-43-1jmwba1.stl, flat_actuators_second20251113-43-1qi1enx.stl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]
2026-01-30 Full flat pneumatic design with new value design
    Help to visualize and with new schematic conner made
2026-02-11 Mega changes on the schematics and pcb
    [RC0402FR-07210RL.step, RC0402JR-074K7L.step, Sensor.kicad_pcb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]
2026-02-20 silicone and tpu nodes
    [Assembly 1 - silicone.stl, Assembly 1 - tpu.stl]
2026-02-22 Update main_shell.rs
    Changing main_shell.rs to reflect our groups changes to the esp32 for ble rather than the use of the pi
2026-02-23 migrated esp32 receiver from rust to c++
2026-02-23 updated to store current state and handle raw bytes instead of json
2026-02-23 DeviceManagers should always conform to ObservableObject
2026-02-23 throttle lidar to 30 hz
2026-02-23 fix device scanning by using observed device manager
2026-02-23 lidar display view
2026-02-23 start/stop button (coupled with session logic)
2026-02-23 app view + switch content view to use app view
2026-02-25 Add files via upload
    added esp32 pressure and mux func for 4 nodes
2026-02-26 Pin outputs all driven high for demo
2026-02-26 external ui remote in progress
    Need to add indents for braile and designs for buttons itself
    [external-ui-remote-v.01.stl]
2026-03-11 Fixed footprints and redid valve pcb
    [Sensor_and_Valve.kicad_pcb]
2026-03-23 Added DiffGainAmp KiCad w/ gerber and drill files
    [DiffGainAmpI2C-B_Cu.gbr, DiffGainAmpI2C-B_Mask.gbr, DiffGainAmpI2C-B_Silkscreen.gbr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]
2026-04-08 redid nodes
    thinner and with 8 nodes
    [new-grid-8.stl]
2026-04-22 use session manager for BLE LiDAR sessions
2026-04-22 observe changes in device connection, manage sessions thru SessionManager
2026-04-22 method to announce LiDAR reconnects
